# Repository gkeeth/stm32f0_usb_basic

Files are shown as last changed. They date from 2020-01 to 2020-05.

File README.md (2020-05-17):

# stm32f0_usb_basic
Basic development board for STM32F042K6Tx (USB line)

No frills, basic dev board for STM32F0 USB line. Has a user button, two user LEDs, all GPIOs broken out, and not much else.

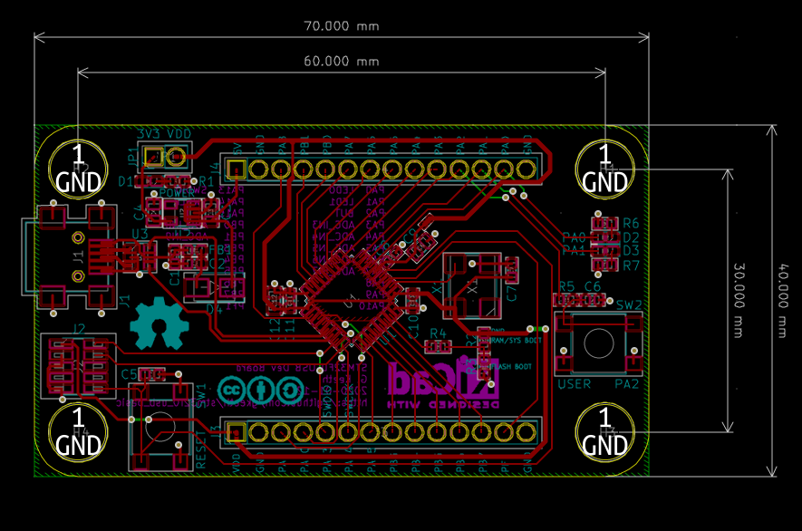
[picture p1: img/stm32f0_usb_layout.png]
layout

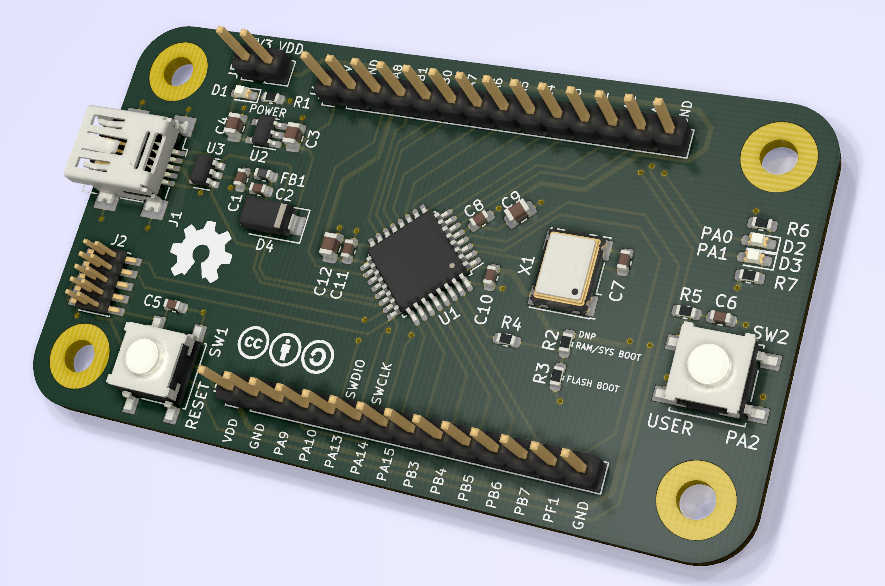
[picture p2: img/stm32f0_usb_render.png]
render


Unless otherwise noted, all hardware is licensed under a [Creative Commons Attribution-ShareAlike 4.0 International License][cc-by-sa] and all software is licensed under the [LGPLv3][lgpl].

[][cc-by-sa]
[][lgpl]

[cc-by-sa]: http://creativecommons.org/licenses/by-sa/4.0/
[cc-by-sa-image]: https://licensebuttons.net/l/by-sa/4.0/88x31.png
[lgpl]: https://www.gnu.org/licenses/lgpl-3.0
[lgpl-image]: https://img.shields.io/badge/License-LGPLv3-blue.svg

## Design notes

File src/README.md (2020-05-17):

Basic application examples for stm32f0_usb board.

Examples are largely adapted from libopencm3 examples and are licensed under the LGPLv3.

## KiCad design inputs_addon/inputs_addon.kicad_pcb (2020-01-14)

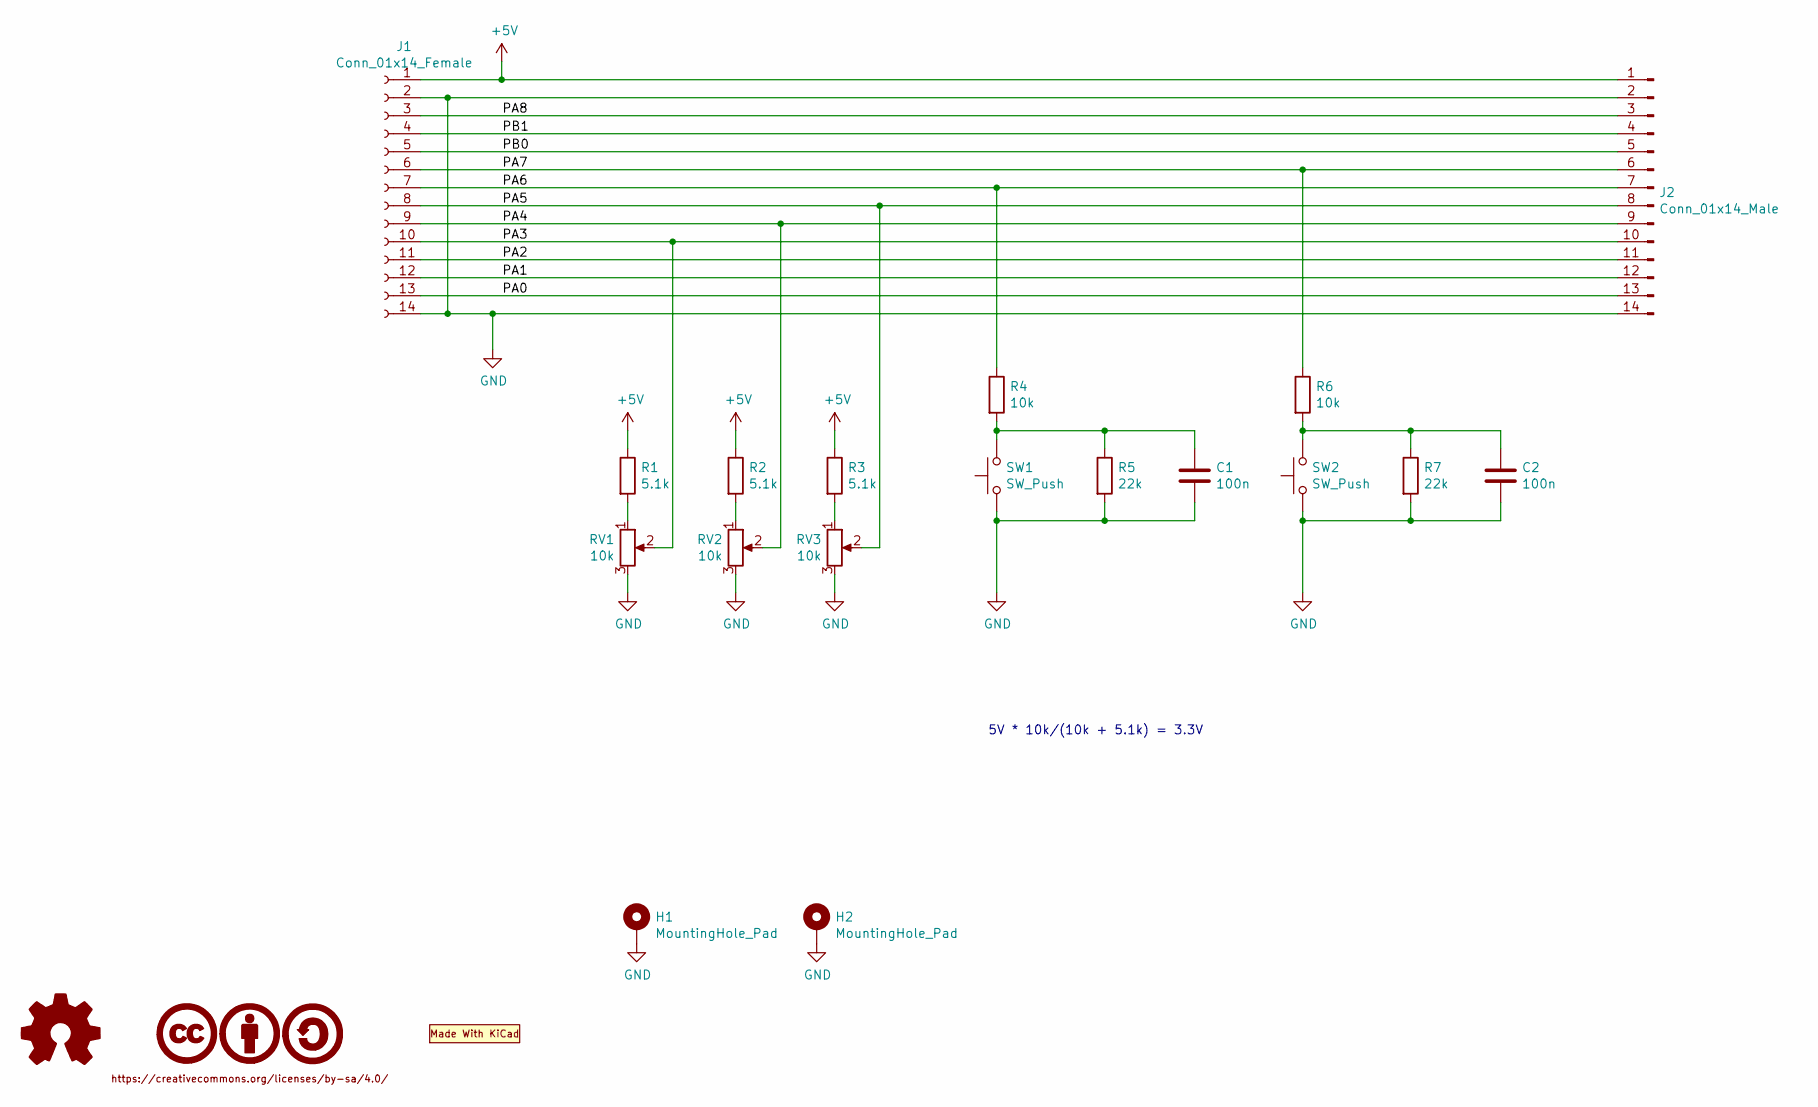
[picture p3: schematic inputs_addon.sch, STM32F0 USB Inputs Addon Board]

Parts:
C1, C2: 100n; C_0603_1608Metric
H1, H2: MountingHole_Pad; MountingHole_3.2mm_M3_Pad
J1: Conn_01x14_Female; PinSocket_1x14_P2.54mm_Vertical
J2: Conn_01x14_Male; PinHeader_1x14_P2.54mm_Vertical
LOGO1: Logo_Open_Hardware_Small; OSHW-Logo_5.7x6mm_SilkScreen
LOGO2: CC-BY-SA_0.33in; CC-BY-SA_SilkScreenTop_Small
LOGO3: Logo_MadeWithKiCad; KiCad-Logo2_5mm_SilkScreen
R1, R2, R3: 5.1k; R_0603_1608Metric
R4, R6: 10k; R_0603_1608Metric
R5, R7: 22k; R_0603_1608Metric
RV1, RV2, RV3: 10k; Potentiometer_Bourns_PTV09A-1_Single_Vertical; Manufacturer PN PTV09A-4020F-B103‎
SW1, SW2: SW_Push; SW_SPST_B3S-1000

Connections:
+5V: J1.1, J2.1, R1.1, R2.1, R3.1
/PA0: J1.13, J2.13
/PA1: J1.12, J2.12
/PA2: J1.11, J2.11
/PA3: J1.10, J2.10, RV1.2
/PA4: J1.9, J2.9, RV2.2
/PA5: J1.8, J2.8, RV3.2
/PA6: J1.7, J2.7, R4.1
/PA7: J1.6, J2.6, R6.1
/PA8: J1.3, J2.3
/PB0: J1.5, J2.5
/PB1: J1.4, J2.4
GND: C1.2, C2.2, H1.1, H2.1, J1.2, J1.14, J2.2, J2.14, R5.2, R7.2, RV1.3, RV2.3, RV3.3, SW1.1, SW2.1
unnamed: C1.1, R4.2, R5.1, SW1.2
unnamed: C2.1, R6.2, R7.1, SW2.2
unnamed: R1.2, RV1.1
unnamed: R2.2, RV2.1
unnamed: R3.2, RV3.1

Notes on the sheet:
5V * 10k/(10k + 5.1k) = 3.3V

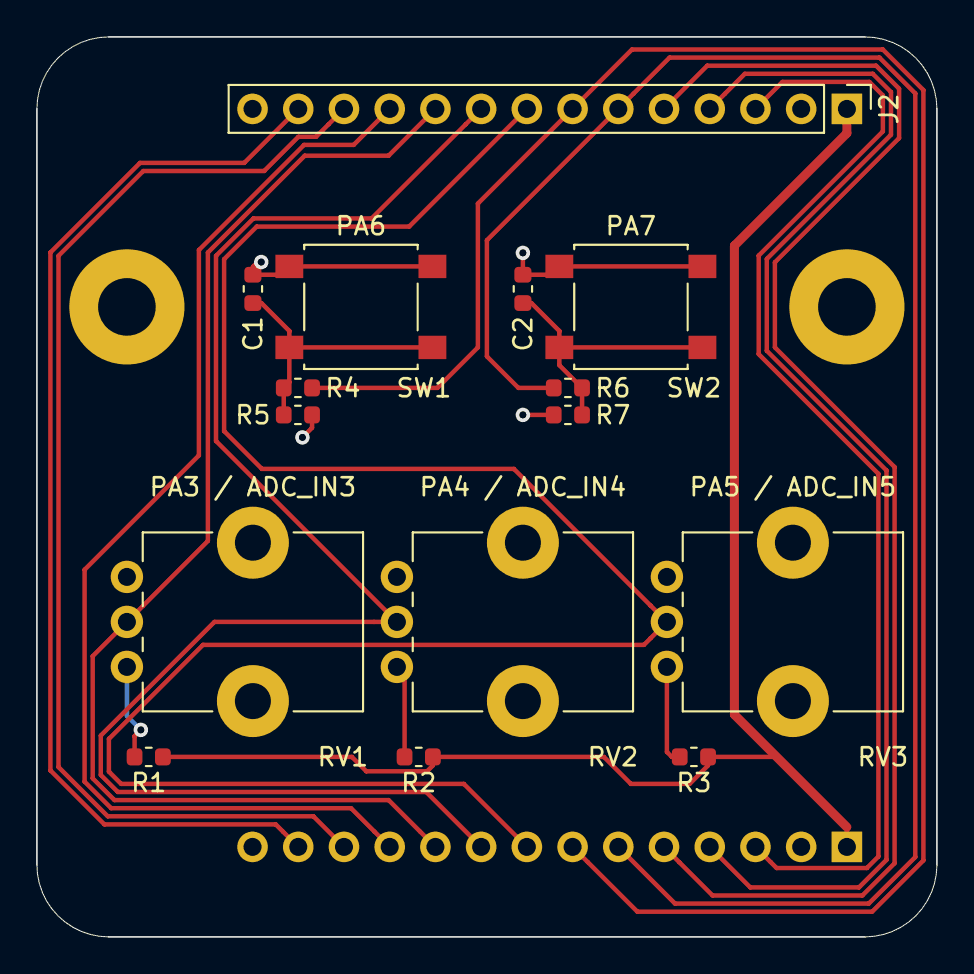
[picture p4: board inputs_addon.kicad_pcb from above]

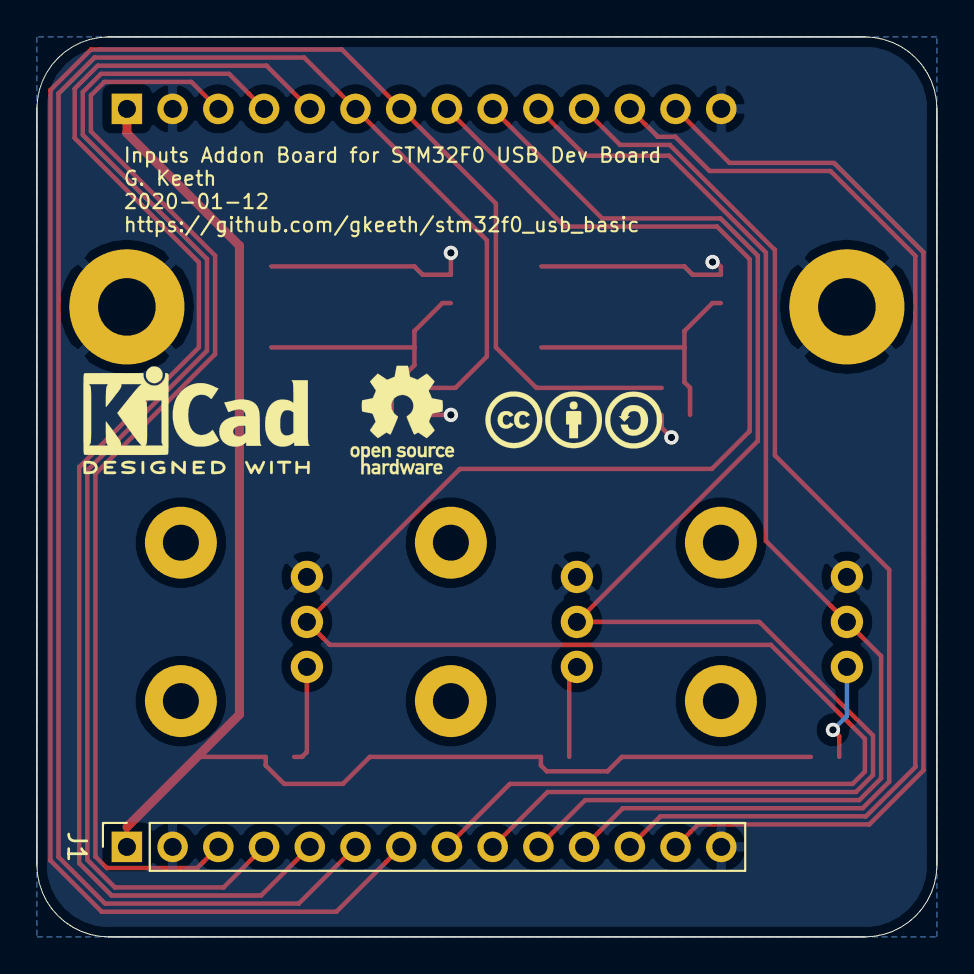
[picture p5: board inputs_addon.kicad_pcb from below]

Board: 2 copper layers, 50.0 x 50.0 mm, 21 parts (4 on the bottom side), 18 nets.

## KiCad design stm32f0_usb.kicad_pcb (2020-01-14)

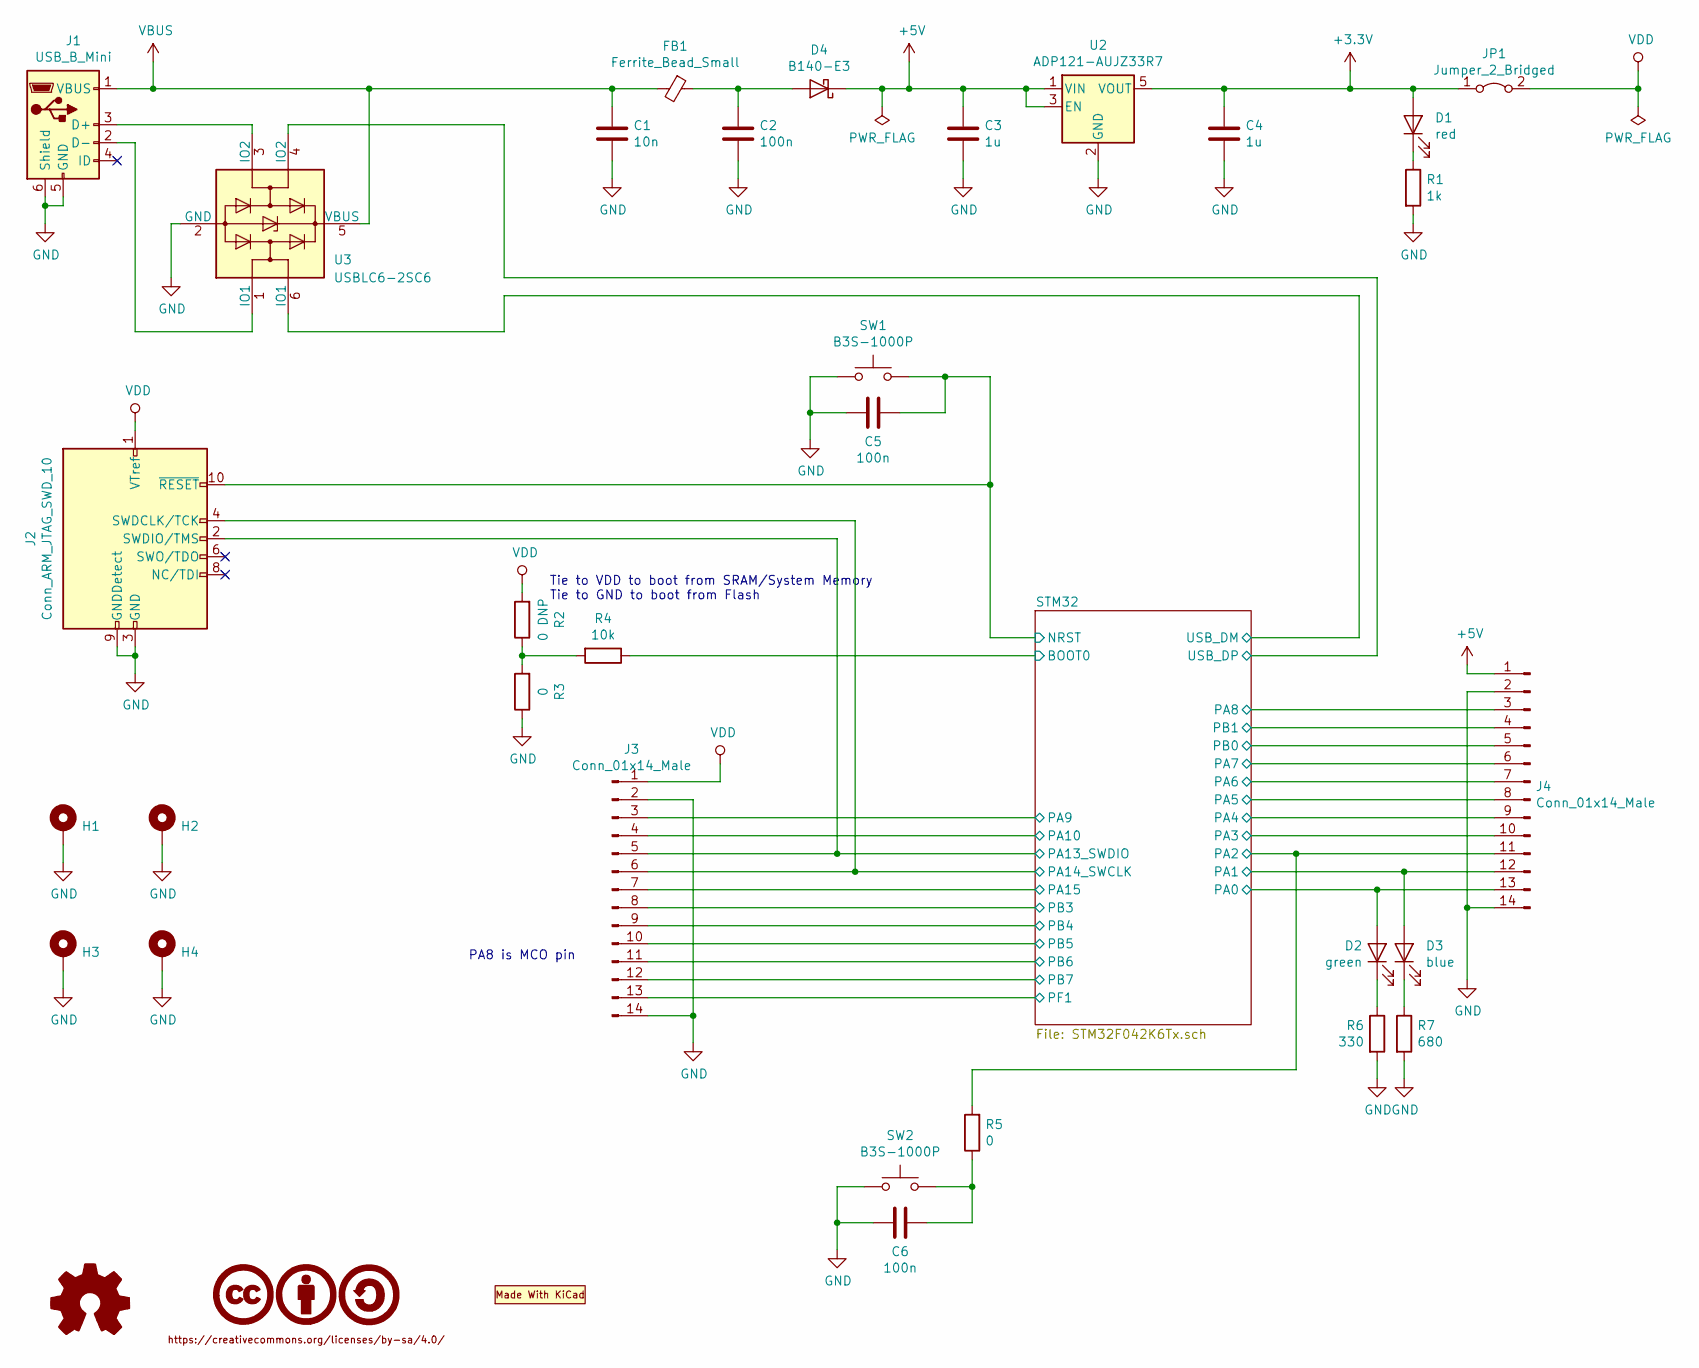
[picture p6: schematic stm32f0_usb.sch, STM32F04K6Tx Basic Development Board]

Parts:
C1: 10n; C_0603_1608Metric
C2, C5, C6: 100n; C_0603_1608Metric
C3, C4: 1u; C_0805_2012Metric
D1: red; LED_0603_1608Metric_Castellated
D2: green; LED_0603_1608Metric_Castellated
D3: blue; LED_0603_1608Metric_Castellated
D4: B140-E3; D_SMA
FB1: Ferrite_Bead_Small; L_0603_1608Metric
H1, H2, H3, H4: MountingHole_Pad; MountingHole_3.2mm_M3_Pad
J1: USB_B_Mini; USB_Mini-B_Wuerth_65100516121_Horizontal
J2: Conn_ARM_JTAG_SWD_10; PinHeader_2x05_P1.27mm_Vertical_SMD
J3, J4: Conn_01x14_Male; PinHeader_1x14_P2.54mm_Vertical
JP1: Jumper_2_Bridged; PinHeader_1x02_P2.54mm_Vertical
LOGO1: Logo_MadeWithKiCad; KiCad-Logo2_5mm_SilkScreen
LOGO2: CC-BY-SA_0.33in; CC-BY-SA_SilkScreenTop_Small
LOGO3: Logo_Open_Hardware_Small; OSHW-Symbol_6.7x6mm_SilkScreen
R1: 1k; R_0603_1608Metric
R2: 0 DNP; R_0603_1608Metric
R3, R5: 0; R_0603_1608Metric
R4: 10k; R_0603_1608Metric
R6: 330; R_0603_1608Metric
R7: 680; R_0603_1608Metric
SW1, SW2: B3S-1000P; SW_SPST_B3S-1000
U2: ADP121-AUJZ33R7; TSOT-23-5
U3: USBLC6-2SC6; SOT-23-6

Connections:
+3V3: C4.1, D1.2 (A), JP1.1 (A), U2.5 (VOUT)
+5V: C3.1, D4.1 (K), J4.1, U2.1 (VIN), U2.3 (EN)
/STM32/BOOT0: R4.1; also elsewhere on the board
/STM32/NRST: C5.1, J2.10 (~RESET~), SW1.2; also elsewhere on the board
/STM32/PA0: D2.2 (A), J4.13; also elsewhere on the board
/STM32/PA1: D3.2 (A), J4.12; also elsewhere on the board
/STM32/PA2: J4.11, R5.2; also elsewhere on the board
/STM32/PA3: J4.10; also elsewhere on the board
/STM32/PA4: J4.9; also elsewhere on the board
/STM32/PA5: J4.8; also elsewhere on the board
/STM32/PA6: J4.7; also elsewhere on the board
/STM32/PA7: J4.6; also elsewhere on the board
/STM32/PA8: J4.3; also elsewhere on the board
/STM32/PA9: J3.3; also elsewhere on the board
/STM32/PA10: J3.4; also elsewhere on the board
/STM32/PA13_SWDIO: J2.2 (SWDIO/TMS), J3.5; also elsewhere on the board
/STM32/PA14_SWCLK: J2.4 (SWDCLK/TCK), J3.6; also elsewhere on the board
/STM32/PA15: J3.7; also elsewhere on the board
/STM32/PB0: J4.5; also elsewhere on the board
/STM32/PB1: J4.4; also elsewhere on the board
/STM32/PB3: J3.8; also elsewhere on the board
/STM32/PB4: J3.9; also elsewhere on the board
/STM32/PB5: J3.10; also elsewhere on the board
/STM32/PB6: J3.11; also elsewhere on the board
/STM32/PB7: J3.12; also elsewhere on the board
/STM32/PF1: J3.13; also elsewhere on the board
/STM32/USB_DM: U3.6 (IO1); also elsewhere on the board
/STM32/USB_DP: U3.4 (IO2); also elsewhere on the board
GND: C1.2, C2.2, C3.2, C4.2, C5.2, C6.2, H1.1, H2.1, H3.1, H4.1, J1.5 (GND), J1.6 (Shield), J2.3 (GND), J2.5 (GND), J2.9 (GNDDetect), J3.2, J3.14, J4.2, J4.14, R1.2, R3.1, R6.2, R7.2, SW1.1, SW2.1, U2.2 (GND), U3.2 (GND); also elsewhere on the board
unnamed: C2.1, D4.2 (A), FB1.1
unnamed: C6.1, R5.1, SW2.2
unnamed: D1.1 (K), R1.1
unnamed: D2.1 (K), R6.1
unnamed: D3.1 (K), R7.1
unnamed: J1.2 (D-), U3.1 (IO1)
unnamed: J1.3 (D+), U3.3 (IO2)
unnamed: R2.1, R3.2, R4.2
VBUS: C1.1, FB1.2, J1.1 (VBUS), U3.5 (VBUS)
VDD: J2.1 (VTref), J3.1, JP1.2 (B), R2.2; also elsewhere on the board

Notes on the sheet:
PA8 is MCO pin
Tie to VDD to boot from SRAM/System Memory Tie to GND to boot from Flash

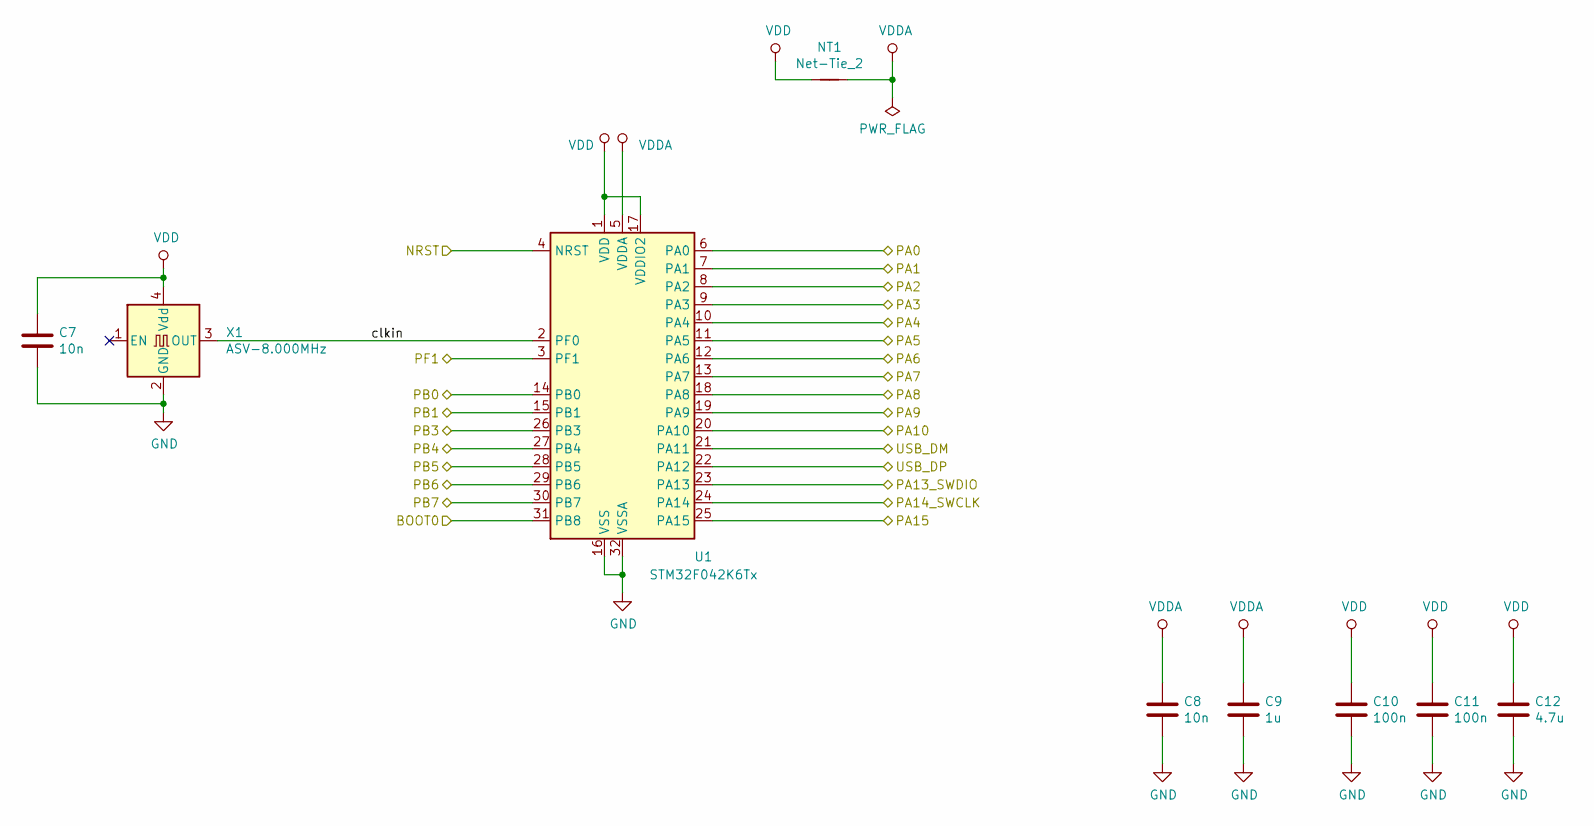
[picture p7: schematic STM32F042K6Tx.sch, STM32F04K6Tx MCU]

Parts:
C7, C8: 10n; C_0603_1608Metric
C9: 1u; C_0805_2012Metric
C10, C11: 100n; C_0603_1608Metric
C12: 4.7u; C_0805_2012Metric
NT1: Net-Tie_2; NetTie-2_SMD_Pad0.5mm
U1: STM32F042K6Tx; LQFP-32_7x7mm_P0.8mm
X1: ASV-8.000MHz; Oscillator_SMD_Abracon_ASV-4Pin_7.0x5.1mm

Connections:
/STM32/BOOT0: U1.31 (PB8); also elsewhere on the board
/STM32/NRST: U1.4 (NRST); also elsewhere on the board
/STM32/PA0: U1.6 (PA0); also elsewhere on the board
/STM32/PA1: U1.7 (PA1); also elsewhere on the board
/STM32/PA2: U1.8 (PA2); also elsewhere on the board
/STM32/PA3: U1.9 (PA3); also elsewhere on the board
/STM32/PA4: U1.10 (PA4); also elsewhere on the board
/STM32/PA5: U1.11 (PA5); also elsewhere on the board
/STM32/PA6: U1.12 (PA6); also elsewhere on the board
/STM32/PA7: U1.13 (PA7); also elsewhere on the board
/STM32/PA8: U1.18 (PA8); also elsewhere on the board
/STM32/PA9: U1.19 (PA9); also elsewhere on the board
/STM32/PA10: U1.20 (PA10); also elsewhere on the board
/STM32/PA13_SWDIO: U1.23 (PA13); also elsewhere on the board
/STM32/PA14_SWCLK: U1.24 (PA14); also elsewhere on the board
/STM32/PA15: U1.25 (PA15); also elsewhere on the board
/STM32/PB0: U1.14 (PB0); also elsewhere on the board
/STM32/PB1: U1.15 (PB1); also elsewhere on the board
/STM32/PB3: U1.26 (PB3); also elsewhere on the board
/STM32/PB4: U1.27 (PB4); also elsewhere on the board
/STM32/PB5: U1.28 (PB5); also elsewhere on the board
/STM32/PB6: U1.29 (PB6); also elsewhere on the board
/STM32/PB7: U1.30 (PB7); also elsewhere on the board
/STM32/PF1: U1.3 (PF1); also elsewhere on the board
/STM32/USB_DM: U1.21 (PA11); also elsewhere on the board
/STM32/USB_DP: U1.22 (PA12); also elsewhere on the board
/STM32/clkin: U1.2 (PF0), X1.3 (OUT)
GND: C7.2, C8.2, C9.2, C10.2, C11.2, C12.2, U1.16 (VSS), U1.32 (VSSA), X1.2 (GND); also elsewhere on the board
VDD: C7.1, C10.1, C11.1, C12.1, NT1.1, U1.1 (VDD), U1.17 (VDDIO2), X1.4 (Vdd); also elsewhere on the board
VDDA: C8.1, C9.1, NT1.2, U1.5 (VDDA)

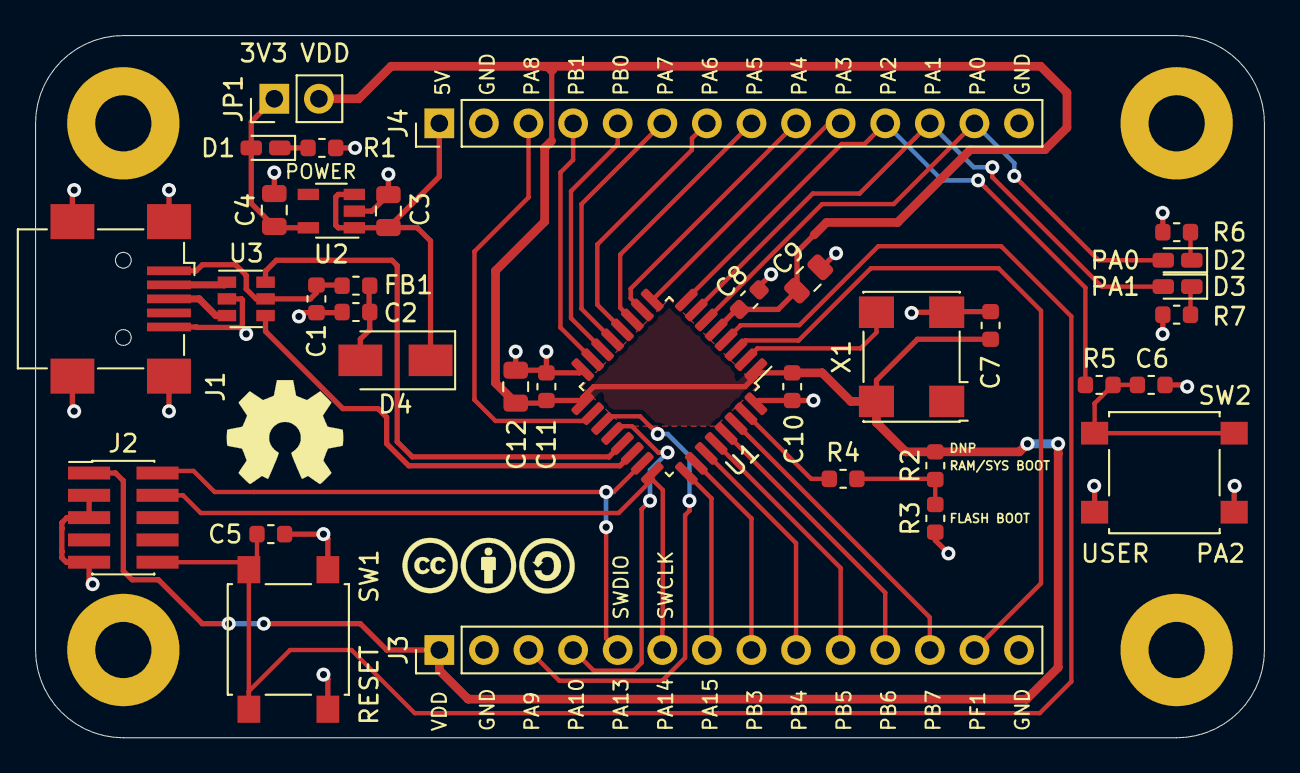
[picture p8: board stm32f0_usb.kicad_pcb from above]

Board: 2 copper layers, 70.0 x 40.0 mm, 43 parts (1 on the bottom side), 41 nets.

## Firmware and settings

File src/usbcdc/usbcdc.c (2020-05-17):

/*
 * USB CDC_ACM example
 *
 * based on libopencm3 usb_simple, usb_cdcacm examples
 *
 * original author:
 * Copyright (C) 2010 Gareth McMullin <gareth@blacksphere.co.nz>
 *
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
 * You should have received a copy of the GNU Lesser General Public License
 * along with this library.  If not, see <http://www.gnu.org/licenses/>.
 */

/*
 * Descriptor Organization:
 *
 * Device Descriptor
 *      Configuration Descriptor
 *              Interface Descriptor
 *                      Endpoint Descriptor
 * Device:
 * - Class: 0x2 (CDC)
 * - Subclass: 0 (reserved, TODO: try 02=ACM?)
 * - Device Protocol: 0 (no protocol required, TODO: try 01=AT protocol)
 * - Endpoint0 packet size: 64
 * - Vendor: 0xCAFE
 * - Product: 0xCAFE
 * - Device: 0x0200
 * - Manufacturer String Index: 1
 * - Product String Index: 2
 * - Serial Number Index: 3
 * - Number of Configurations: 1
 *
 *   Configuration:
 *   - Number of Interfaces: 2
 *   - Configuration Number: 1
 *   - Configuration String Index: 0 (N/A)
 *   - Configuration Attributes: 0x80 (bus powered)
 *   - Configuration Max Power: 0x32 (100mA)
 *
 *     Communications Interface:
 *     - interface number: 0
 *     - alternate setting: 0
 *     - number of endpoints: 1
 *     - interface class: CDC
 *     - interface subclass: ACM
 *     - interface protocol: AT
 *     - interface string index: 0 (N/A)
 *
 *       Management Endpoint:
 *       - address: 0x83 (input, endpoint3)
 *       - attributes: Interrupt
 *       - packet size: 16
 *       - interval: 255
 *
 *     Data Interface:
 *     - interface number: 1
 *     - alternate setting: 0
 *     - number of endpoints: 2
 *     - interface class: data
 *     - interface subclass: 0
 *     - interface protocol: 0
 *     - interface string index: 0 (N/A)
 *
 *       Data Endpoint 1:
 *       - address: 0x01 (output, endpoint1)
 *       - attributes: bulk
 *       - packet size: 64
 *       - interval: 1
 *
 *       Data Endpoint 2:
 *       - address: 0x82 (input, endpoint2)
 *       - attributes: bulk
 *       - packet size: 64
 *       - interval: 1
 *
 */

#include <stdlib.h>
#include <libopencm3/stm32/rcc.h>
#include <libopencm3/stm32/gpio.h>
#include <libopencm3/stm32/usart.h>
#include <libopencm3/cm3/nvic.h>
#include <libopencm3/cm3/systick.h>
#include <libopencm3/stm32/flash.h>
#include <libopencm3/usb/usbd.h>
#include <libopencm3/usb/cdc.h>

/* LEDs are on PA0 and PA1 */
#define PORT_LED GPIOA
#define PIN_LED0 GPIO0
#define PIN_LED1 GPIO1

/* user button is on PA2 */
#define PORT_BUT GPIOA
#define PIN_BUT GPIO2

/* USB pins are on PA11/PA12 */
#define PORT_USB GPIOA
#define PIN_USBDM GPIO11
#define PIN_USBDP GPIO12

volatile uint32_t counter = 0;

void sys_tick_handler(void) {
    ++counter;
}

uint32_t millis(void);
uint32_t millis(void) {
    return counter;
}

const struct usb_device_descriptor dev = {
    .bLength = USB_DT_DEVICE_SIZE,
    .bDescriptorType = USB_DT_DEVICE, /* device descriptor */
    .bcdUSB = 0x0200,                 /* USB 2.0 */
    .bDeviceClass = USB_CLASS_CDC,    /* vendor-specified class code */
    .bDeviceSubClass = 0,             /* subclass 0 */
    .bDeviceProtocol = 0,             /* device protocol 0 */
    .bMaxPacketSize0 = 64,            /* max packet size for endpoint 0 */
    .idVendor = 0xCAFE,               /* vendor ID */
    .idProduct = 0xCAFE,              /* product ID */
    .bcdDevice = 0x0200,              /* Device Release Number (2.0?) */
    .iManufacturer = 1,               /* Manufacturer string is at index 1 */
    .iProduct = 2,                    /* product string is at index 2 */
    .iSerialNumber = 3,               /* serial number string is at index 3 */
    .bNumConfigurations = 1,          /* only 1 configuration */
};

/* communications notification endpoint
 * libopencm3 example notes that linux cdc_acm driver requires this even
 * though it isn't necessary per USB CDC spec. */
#define ENDPOINT_ADDR_COMM_INPUT 0x83
#define PACKET_SIZE_COMM 16
static const struct usb_endpoint_descriptor comm_endp[] = {{
    .bLength = USB_DT_ENDPOINT_SIZE,
    .bDescriptorType = USB_DT_ENDPOINT,
    .bEndpointAddress = ENDPOINT_ADDR_COMM_INPUT,
    .bmAttributes = USB_ENDPOINT_ATTR_INTERRUPT,
    .wMaxPacketSize = PACKET_SIZE_COMM,
    .bInterval = 255,
}};

/* data endpoints */
#define ENDPOINT_ADDR_DATA_OUTPUT 0x01
#define ENDPOINT_ADDR_DATA_INPUT 0x82
#define PACKET_SIZE_DATA 64
static const struct usb_endpoint_descriptor data_endp[] = {{
    .bLength = USB_DT_ENDPOINT_SIZE,
    .bDescriptorType = USB_DT_ENDPOINT,
    .bEndpointAddress = ENDPOINT_ADDR_DATA_OUTPUT,
    .bmAttributes = USB_ENDPOINT_ATTR_BULK,
    .wMaxPacketSize = PACKET_SIZE_DATA,
    .bInterval = 1,
}, {
    .bLength = USB_DT_ENDPOINT_SIZE,
    .bDescriptorType = USB_DT_ENDPOINT,
    .bEndpointAddress = ENDPOINT_ADDR_DATA_INPUT,
    .bmAttributes = USB_ENDPOINT_ATTR_BULK,
    .wMaxPacketSize = PACKET_SIZE_DATA,
    .bInterval = 1,
}};


/* CDC Functional Descriptors, USBCDC1.2 section 5.2.3 */
static const struct {
    struct usb_cdc_header_descriptor header;
    struct usb_cdc_call_management_descriptor call_mgmt;
    struct usb_cdc_acm_descriptor acm;
    struct usb_cdc_union_descriptor cdc_union;
} __attribute__((packed)) cdcacm_functional_descriptors = {
    .header = { /* USBCDC1.2 section 5.2.3.1 */
        .bFunctionLength = sizeof(struct usb_cdc_header_descriptor),
        .bDescriptorType = CS_INTERFACE,
        .bDescriptorSubtype = USB_CDC_TYPE_HEADER,
        .bcdCDC = 0x0120, /* CDC Specification version 1.2 */
    },
    .call_mgmt = { /* PSTN1.2 section 5.3.1 */
        .bFunctionLength = sizeof(struct usb_cdc_call_management_descriptor),
        .bDescriptorType = CS_INTERFACE,
        .bDescriptorSubtype = USB_CDC_TYPE_CALL_MANAGEMENT,
        .bmCapabilities = 0, /* device doesn't handle call management*/
        .bDataInterface = 1, /* muxed commands handled by data_iface */
    },
    .acm = { /* PSTN1.2 section 5.3.2 */
        .bFunctionLength = sizeof(struct usb_cdc_acm_descriptor),
        .bDescriptorType = CS_INTERFACE,
        .bDescriptorSubtype = USB_CDC_TYPE_ACM,
        /* support SET/GET_LINE_CODING, SET_CONTROL_LINE_STATE, SERIAL_STATE */
        .bmCapabilities = 0x2,
    },
    .cdc_union = { /* USBCDC1.2 section 5.2.3.2 */
        .bFunctionLength = sizeof(struct usb_cdc_union_descriptor),
        .bDescriptorType = CS_INTERFACE,
        .bDescriptorSubtype = USB_CDC_TYPE_UNION,
        .bControlInterface = 0, /* control interface is comm_iface */
        .bSubordinateInterface0 = 1, /* data_iface */
    }
};

const struct usb_interface_descriptor comm_iface[] = {{
    .bLength = USB_DT_INTERFACE_SIZE,
    .bDescriptorType = USB_DT_INTERFACE,
    .bInterfaceNumber = 0,
    .bAlternateSetting = 0,         /* alternate setting 0 for iface0 */
    .bNumEndpoints = 1,             /* one endpoint (besides default) */
    .bInterfaceClass = USB_CLASS_CDC,
    .bInterfaceSubClass = USB_CDC_SUBCLASS_ACM,
    .bInterfaceProtocol = USB_CDC_PROTOCOL_AT,
    .iInterface = 0,                /* interface string is at index 0 (N/A) */

    .endpoint = comm_endp,

    /* communications class-specific descriptor information */
    .extra = &cdcacm_functional_descriptors,
    .extralen = sizeof(cdcacm_functional_descriptors)
}};

const struct usb_interface_descriptor data_iface[] = {{
    .bLength = USB_DT_INTERFACE_SIZE,
    .bDescriptorType = USB_DT_INTERFACE,
    .bInterfaceNumber = 1,
    .bAlternateSetting = 0,         /* alternate setting 0 for iface1 */
    .bNumEndpoints = 2,             /* two endpoints: one input, one output*/
    .bInterfaceClass = USB_CLASS_DATA,
    .bInterfaceSubClass = 0,
    .bInterfaceProtocol = 0,
    .iInterface = 0,                /* interface string is at index 0 (N/A) */

    .endpoint = data_endp,

    /* data class does not define class-specific descriptor information */
}};

/* libopencm3 docs say this should not need to be implemented in user code.
 * However, this is the only way interfaces are specified, and it doesn't work
 * without this */
const struct usb_interface ifaces[] = {{
    .num_altsetting = 1,
    .altsetting = comm_iface,
}, {
    .num_altsetting = 1,
    .altsetting = data_iface,
}};


const struct usb_config_descriptor config = {
    .bLength = USB_DT_CONFIGURATION_SIZE,
    .bDescriptorType = USB_DT_CONFIGURATION,
    .wTotalLength = 0, /* automatically calculated by driver */
    .bNumInterfaces = 2,
    .bConfigurationValue = 1,
    .iConfiguration = 0,        /* no configuration string provided */
    .bmAttributes = 0x80,       /* bus powered */
    .bMaxPower = 0x32,          /* 100mA (50 * 2mA) */

    .interface = ifaces,
};

const char *usb_strings[] = {
    "gkeeth technologies", /* manufacturer */
    "first test",          /* product */
    "1234",                /* serial number */
};

/* buffer for control requests */
uint8_t usbd_control_buffer[128];

/* hardcode line coding */
static const struct usb_cdc_line_coding line_coding = {
    .dwDTERate = 115200,
    .bCharFormat = USB_CDC_1_STOP_BITS,
    .bParityType = USB_CDC_NO_PARITY,
    .bDataBits = 0x08,
};

#define USB_CDC_REQ_GET_LINE_CODING 0x21 /* not defined in usbcdc.h */
static enum usbd_request_return_codes cdcacm_control_request(
        usbd_device *usbd_dev, struct usb_setup_data *req,
        uint8_t **buf, uint16_t *len,
        void (**complete)(usbd_device *usbd_dev, struct usb_setup_data *req)) {
    /* avoid compiler warnings */
    (void) buf;
    (void) complete;
    (void) usbd_dev;

    switch (req->bRequest) {
    case USB_CDC_REQ_SET_CONTROL_LINE_STATE: {
        char local_buf[10];
        struct usb_cdc_notification *notif = (void *)local_buf;

        /* echo signals back to host */
        notif->bmRequestType = 0xA1; /* D-to-H, class, interface (USB9.3) */
        notif->bNotification = USB_CDC_NOTIFY_SERIAL_STATE;
        notif->wValue = 0;
        notif->wIndex = 0;
        notif->wLength = 2;
        local_buf[8] = req->wValue & 3;
        local_buf[9] = 0;
        usbd_ep_write_packet(usbd_dev, ENDPOINT_ADDR_COMM_INPUT, local_buf, 10);

        /* not a real transceiver, so no RTS/DTE lines to do anything with */
        return USBD_REQ_HANDLED;
    }
    case USB_CDC_REQ_SET_LINE_CODING:
        if (*len < sizeof(struct usb_cdc_line_coding)) {
            return USBD_REQ_NOTSUPP;
        }
        return USBD_REQ_HANDLED;
    case USB_CDC_REQ_GET_LINE_CODING:
        *buf = (uint8_t *) &line_coding;
        /* TODO: is buf automatically sent in a control transfer after return?
         * trace out call graph
         */
        return USBD_REQ_HANDLED;
    }

    return USBD_REQ_NOTSUPP;
}

static void cdcacm_data_rx_cb(usbd_device *usbd_dev, uint8_t ep) {
    (void) ep; /* avoid compiler warning */

    const int BUFSIZE = 64;
    char buf[BUFSIZE];

    /* read data from host */
    int len = usbd_ep_read_packet(usbd_dev, ENDPOINT_ADDR_DATA_OUTPUT, buf, BUFSIZE);
    if (len) {
        /* Toggle LED */
        gpio_toggle(PORT_LED, PIN_LED0);

        /* echo back to host
         * (boring demo behavior) */
        usbd_ep_write_packet(usbd_dev, ENDPOINT_ADDR_DATA_INPUT, buf, len);
        buf[len] = 0;
    }
}

/* callback for "set config"
 * on every "set config", this callback will register a "control" callback */
static void cdcacm_set_config(usbd_device *usbd_dev, uint16_t wValue) {
    (void) wValue; /* avoid compiler warning */

    usbd_ep_setup(usbd_dev, ENDPOINT_ADDR_DATA_OUTPUT, USB_ENDPOINT_ATTR_BULK,
                  PACKET_SIZE_DATA, cdcacm_data_rx_cb);
    usbd_ep_setup(usbd_dev, ENDPOINT_ADDR_DATA_INPUT, USB_ENDPOINT_ATTR_BULK,
                  PACKET_SIZE_DATA, NULL);
    usbd_ep_setup(usbd_dev, ENDPOINT_ADDR_COMM_INPUT,
                  USB_ENDPOINT_ATTR_INTERRUPT, PACKET_SIZE_COMM, NULL);

    usbd_register_control_callback(usbd_dev,
            USB_REQ_TYPE_CLASS | USB_REQ_TYPE_INTERFACE,
            USB_REQ_TYPE_TYPE | USB_REQ_TYPE_RECIPIENT,
            cdcacm_control_request);
}

static void setup(void) {
    /* use external 8MHz oscillator to derive 48MHz clock from PLL
     * this is an oscillator, not a crystal, so disable the builtin oscillator
     * circuit (enable oscillator bypass) */
    rcc_osc_bypass_enable(RCC_HSE);
    rcc_clock_setup_in_hse_8mhz_out_48mhz();
    STK_CVR = 0; /* clear systick current value to start immediately */

    /* enable clocks for USB & LED pins
     * clocks for USB peripheral itself are enabled by the USB driver, later */
    rcc_periph_clock_enable(RCC_GPIOA);

    /* Pins for usb don't need to be setup because they are additional
     * functions, not alternate functions */

    /* set LED pins to output push-pull */
    gpio_mode_setup(PORT_LED, GPIO_MODE_OUTPUT, GPIO_PUPD_NONE, PIN_LED0 | PIN_LED1);
}

int main(void) {
    /* USB CDC demo:
     * receive ascii input from serial terminal
     * if input == "on", turn LED on and give feedback to user
     * if input == "off", turn LED off and give feedback to user
     * otherwise, give feedback to user ("invalid command")
     */

    usbd_device *usbd_dev;
    setup();
    usbd_dev = usbd_init(&st_usbfs_v2_usb_driver, &dev, &config, usb_strings, 3,
            usbd_control_buffer, sizeof(usbd_control_buffer));

    usbd_register_set_config_callback(usbd_dev, cdcacm_set_config);

    gpio_clear(PORT_LED, PIN_LED0 | PIN_LED1);

    while (1) {
        usbd_poll(usbd_dev);
    }

    return 0;
}

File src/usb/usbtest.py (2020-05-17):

#! /usr/bin/env python

import usb.core
import time

if __name__ == "__main__":
    dev = usb.core.find(idVendor=0xcafe, idProduct=0xcafe)
    if dev is None:
        raise ValueError('Device not found')

    dev.set_configuration()

    while True:
        print("turning on LED")
        dev.ctrl_transfer(0x40, 0, 1, 0, 'Hello World!')
        time.sleep(0.5)
        print("turning off LED")
        dev.ctrl_transfer(0x40, 0, 0, 0, 'Goodnight World!')
        time.sleep(0.5)

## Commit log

2020-01-10 initial commit. Full initial schematic for board.
    [STM32F042K6Tx.sch, stm32f0_usb.kicad_pcb, stm32f0_usb.sch]
2020-01-11 initial board setup and rough placement
    [stm32f0_usb.kicad_pcb]
2020-01-11 label clkin net
    [STM32F042K6Tx.sch]
2020-01-11 update GPIO/header pinout to ease routing
    [stm32f0_usb.kicad_pcb, stm32f0_usb.sch]
2020-01-11 update usb esd connections
    [stm32f0_usb.kicad_pcb, stm32f0_usb.sch]
2020-01-11 initial routing mostly finished
    [STM32F042K6Tx.sch, stm32f0_usb.kicad_pcb, stm32f0_usb.sch]
2020-01-12 complete routing
    [stm32f0_usb.kicad_pcb, stm32f0_usb.sch]
2020-01-12 fatten power traces, add pinout table, neaten silk
    [stm32f0_usb.kicad_pcb]
2020-01-12 add inputs addon board, fully routed
    [inputs_addon.kicad_pcb, inputs_addon.sch]
2020-01-14 switch to vertical headers, add mounting holes
    [inputs_addon.kicad_pcb, inputs_addon.sch]
2020-01-14 add dimensions to dwgs.user layer
    [stm32f0_usb.kicad_pcb]
2020-01-14 plot outputs for r0
    [stm32f0_usb-B_Cu.gbr, stm32f0_usb-B_Mask.gbr, stm32f0_usb-B_Paste.gbr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]
2020-01-14 plot gerbers for inputs_addon r0
    [inputs_addon-B_Cu.gbr, inputs_addon-B_Mask.gbr, inputs_addon-B_Paste.gbr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]
2020-01-14 refill zones
    [inputs_addon.kicad_pcb]
2020-01-14 update readme with license and board images
2020-01-22 add blink example
    [stm32f0_usb.cfg]
2020-05-17 add blink2 example
    [stm32f0_usb.cfg]
2020-05-17 remove redundant blink2 example
    [stm32f0_usb.cfg]
2020-05-17 add basic usb example
    [stm32f0_usb.cfg]
2020-05-17 functional usbcdc example
    [stm32f0_usb.cfg]
2020-05-17 let driver automatically calculate wTotalLength

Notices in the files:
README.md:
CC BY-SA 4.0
